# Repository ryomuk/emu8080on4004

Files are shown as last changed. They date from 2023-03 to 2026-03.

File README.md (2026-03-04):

# emu8080on4004
Intel 8080 Emulator on 4004 Evaluation Board

This document is written mostly in Japanese.
If necessary, please use a translation service such as DeepL (I recommend this) or Google.

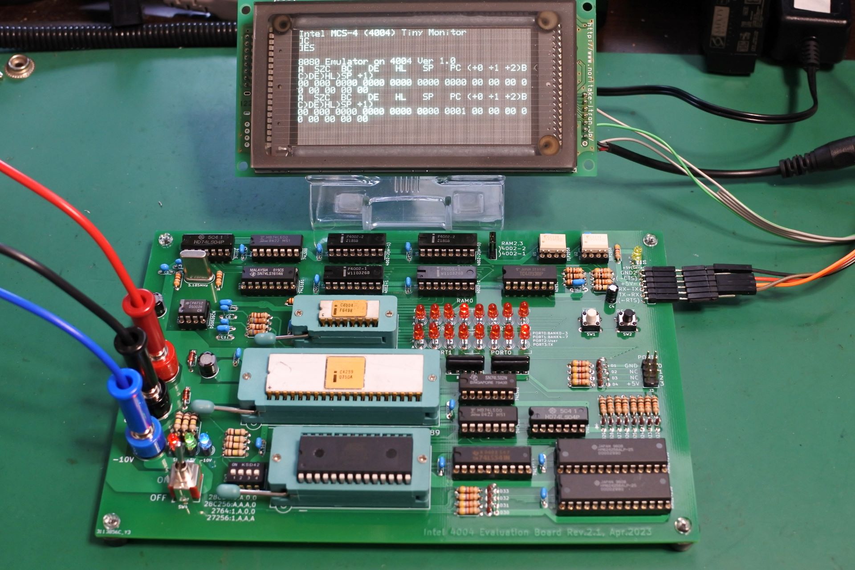
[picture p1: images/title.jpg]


## 概要
自作の4004実験用ボードと，その上で動作する8080エミュレータです．Palo Alot Tiny BASIC(4K整数型BASIC)や，Grant Searle's BASIC(8K浮動小数点BASIC)の8080移植版がほぼそのまま動くレベルの機能が実現できています．動作速度は8080実機の1/700程度です．

## 制限事項等
- P(パリティ)フラグの実装は正確ではありません．{J,C,R}{PO,PE}実行時にAレジスタの値から計算されます．
- DAA命令の実装は正確ではありません．
- IN命令(コントロールレジスタ)はACC=0xFF(データあり)を返します．
- IN命令(データレジスタ)は4004ボードのソフトウェアで実装されたUARTのGETCHARを呼ぶので，入力されるまで止まります．
- OUT命令はAレジスタを4004ボードのシリアルポートに出力します．
- 割り込み関連命令(DI, EI)は未実装です．

## 実験ボードの仕様
### ブレッドボード版プロトタイプの仕様
- CPU: Intel 4004
- Clock: 740kHz
- DATA RAM: 4002-1 x 2 + 4002-2 x 2 (計320bit x 4)
- Program Memory
  - ROM: AT28C64B (8k x 8bit EEPROM)
    - 000H〜EFFHの3.75KB利用可能
  - RAM: HM6268(4k x 4bit SRAM)x 2個
    - 物理メモリ F00H〜FFDHの254byte x 16バンク
      (上記を論理メモリ 000H〜FDFHにマッピングしてアクセス)
- 通信ポート: 9600bps Software Serial UART (TTL level)

### Rev.2.1版の仕様(ブレッドボード版との差分)
- Program Memory
  - DATA RAM: ピンヘッダの設定により4002-1 x 4の構成も可能ですが，その場合はソフトウェアでRAM2, RAM3をアクセスしている部分を修正する必要があります．
  - ROM: AT28C64B, AT28C256, 2764, 27256をDIPスイッチで選択可能なように設計しましたが，動作確認はAT28C64Bで実施．それ以外は未確認です．
  - RAM: HM624256(1Mbit(256k x 4bit) SRAM)x 2個
    - 物理メモリ F00H〜FFDHの254byte x 256バンク
      (上記を論理メモリ 0000H〜FDFFHにマッピングしてアクセス)

## ToDO
- メモリ64KBに拡張 → Rev.2.1で実現(2023/4/12)
- プリント基板作成 → Rev.2.1で実現(2023/4/12)
- IN命令時にTESTキーを使ったSTOPボタン相当の機能の実装

## 動画
Youtubeで関連動画を公開しています．
- https://www.youtube.com/@ryomukai/videos

## ブログ
関連する情報が書いてあるかも．
- [Intel 4004関連記事のまとめ](https://note.com/ryomuk/m/m2f55e2a1f586)

## 4004関連開発事例
- [Intel 4004  50th Anniversary Project](https://www.4004.com/)
  - https://www.4004.com/busicom-replica.html
  - http://www.4004.com/2009/Busicom-141PF-Calculator_asm_rel-1-0-1.txt
- https://github.com/jim11662418/4004-SBC
- https://www.cpushack.com/mcs-4-test-boards-for-sale
- https://github.com/novi/4004MainBoard

## データシート
- http://www.bitsavers.org/components/intel/
- https://www.intel-vintage.info/intelmcs.htm

## 開発環境
- [The Macroassembler AS](http://john.ccac.rwth-aachen.de:8000/as/)

## 画像集
- ブレッドボード版のプロトタイプ
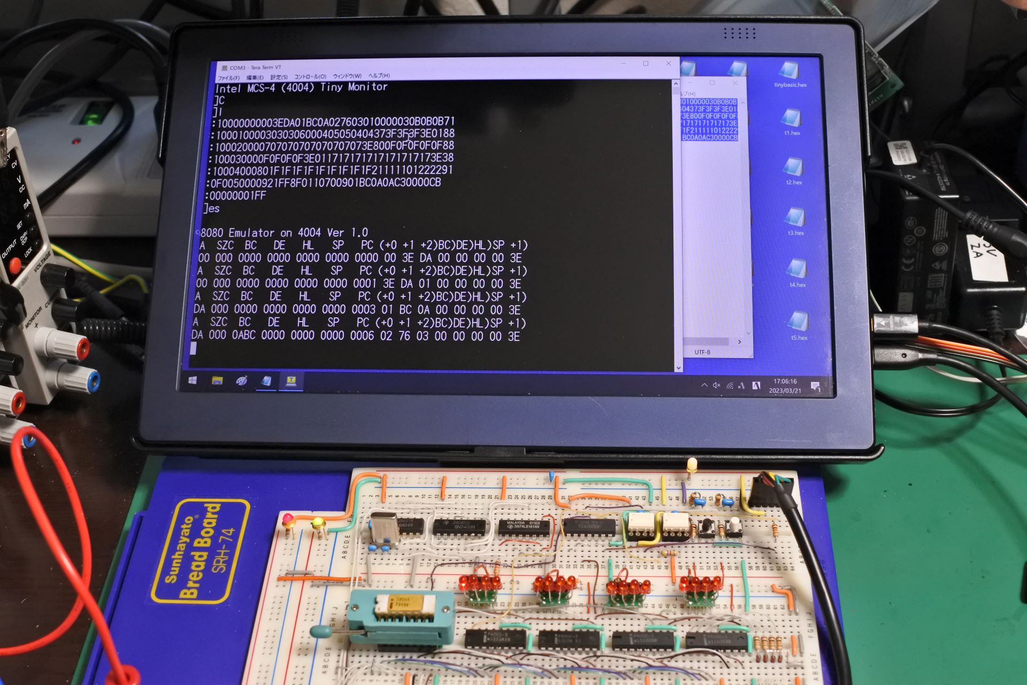
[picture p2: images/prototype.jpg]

- プロトタイプでPalo Alto BASIC実行

- Rev.2.1基板
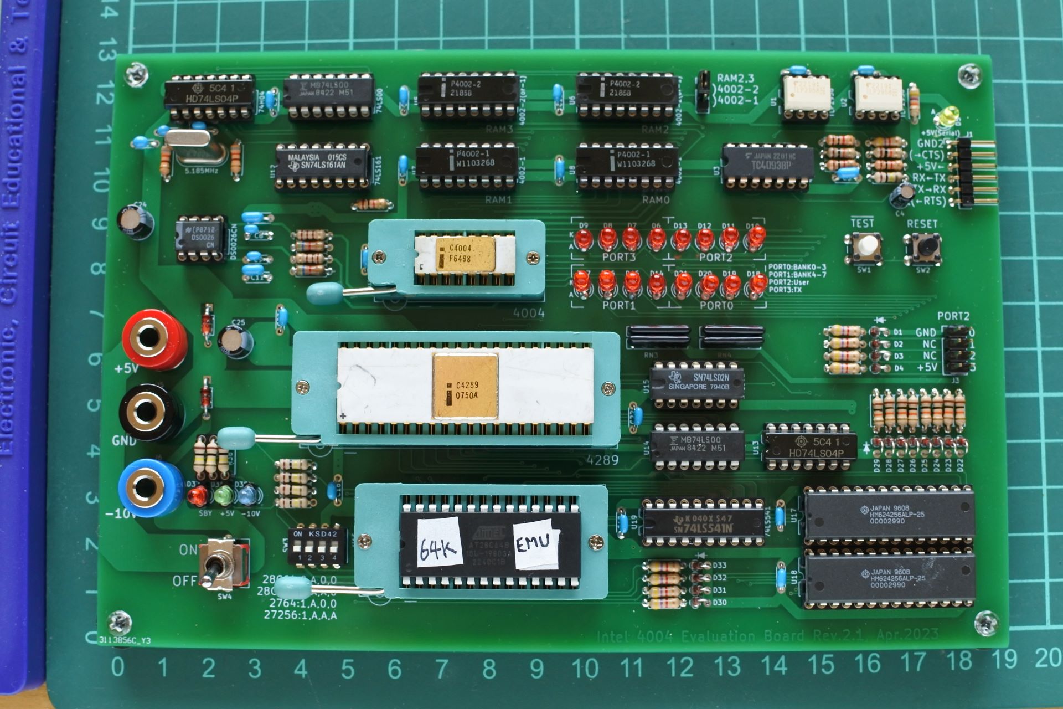
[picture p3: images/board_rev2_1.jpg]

- ブレッドボード版とRev.2.1基板
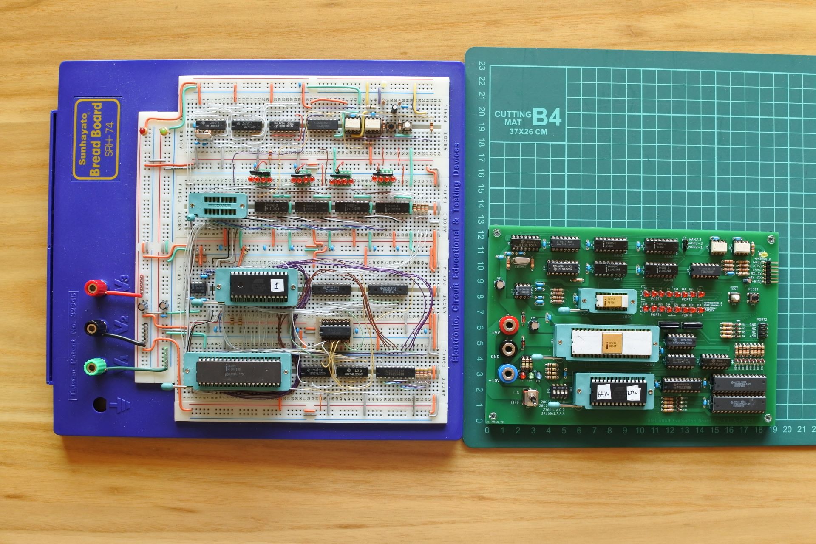
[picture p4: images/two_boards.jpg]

- 8K BASIC 起動画面
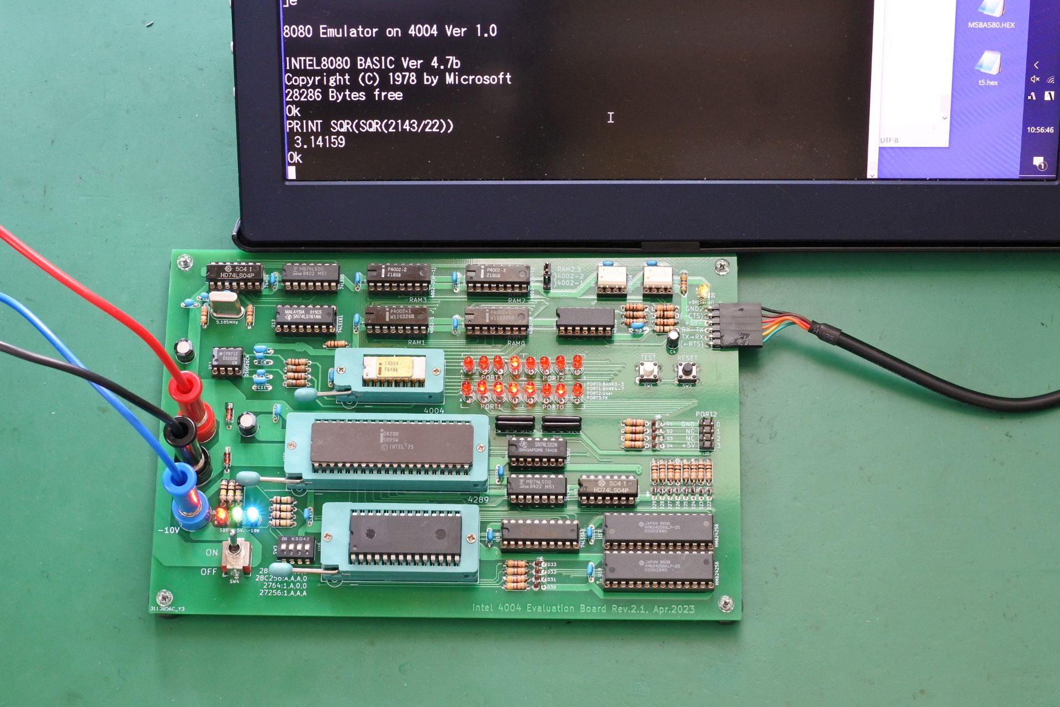
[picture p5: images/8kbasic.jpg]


## 更新履歴
- 2023/3/21: 初版公開
- 2023/4/3: SUBフラグ(NEC uPD8080A, uCOM-80用)に関するコードを削除
- 2023/4/12: 基板(Rev.2.1)に合わせていろいろ更新．ブレッドボード版はprototypeフォルダに移動
- 2023/4/15: emu.asmにレジスタ表示しながらの連続実行とTESTボタンでの停止機能を追加
- 2023/4/16: ADC, ACIにバグ(0+FFH+Carrry(1)でCarryが立たない)があったので修正．

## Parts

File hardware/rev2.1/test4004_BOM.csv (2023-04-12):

# | Reference | Qty | Value | Memo | URL | Footprint | Example | Whare to buy
1 | C1, C2, C5, C6, C13, C14, C15, C16, C17, C18, C19, C20, C21, C22, C23 | 15 | 0.1uF |  | https://akizukidenshi.com/catalog/g/gP-10147/ | 000_MyFootprint:C_Disc_D4.3mm_W1.9mm_P5.00mm
2 | C3, C7, C11 | 3 | 1uF |  | https://akizukidenshi.com/catalog/g/gP-08150/ | 000_MyFootprint:C_Disc_D4.7mm_W2.5mm_P5.00mm
3 | C4 | 1 | 10uF |  | https://akizukidenshi.com/catalog/g/gP-10590/ | 000_MyFootprint:CP_Radial_D4.0mm_P1.50mm
4 | C8, C9, C10 | 3 | 0.01uF |  | https://akizukidenshi.com/catalog/g/gP-10148/ | 000_MyFootprint:C_Disc_D4.3mm_W1.9mm_P5.00mm
5 | C12 | 1 | 50pF | 47pF可 | https://akizukidenshi.com/catalog/g/gP-08045/ | 000_MyFootprint:C_Disc_D4.3mm_W1.9mm_P5.00mm
6 | C24, C25 | 2 | 47uF |  | https://akizukidenshi.com/catalog/g/gP-10596/ | 000_MyFootprint:CP_Radial_D6.3mm_P2.50mm
7 | D1, D2, D3, D4, D22, D23, D24, D25, D26, D27, D28, D29, D30, D31, D32, D33 | 16 | 1N4148 |  | https://akizukidenshi.com/catalog/g/gI-00941/ | 000_MyFootprint:D_DO-35_SOD27_P2.54mm_Vertical_AnodeUp
8 | D5, D34, D37, D38 | 4 | LED | 電源表示用のLED(D5, 37, 34, 38)は任意です。それらに接続される抵抗は適当に変更して下さい。 | https://akizukidenshi.com/catalog/g/gI-16908/ | 000_MyFootprint:LED_D3.0mm
9 | D6, D7, D8, D9, D10, D11, D12, D13, D14, D15, D16, D17, D18, D19, D20, D21 | 16 | LED | 4002のポートに接続されるLEDです。低消費電力なものを使用して下さい。 | https://akizukidenshi.com/catalog/g/gI-16908/ | 000_MyFootprint:LED_D3.0mm
11 | D35 | 1 | Zener6.2V | 電源の逆接続防止用です。無くても動作します。 | https://akizukidenshi.com/catalog/g/gI-07494/ | 000_MyFootprint:D_DO-35_SOD27_P7.62mm_Horizontal
12 | D36 | 1 | Zener12V | 電源の逆接続防止用です。無くても動作します。 | https://akizukidenshi.com/catalog/g/gI-06452/ | 000_MyFootprint:D_DO-35_SOD27_P7.62mm_Horizontal
16 | J1 | 1 | L-pinheader 6P |  |  | 000_MyFootprint:PinHeader_1x06_P2.54mm_Horizontal
17 | J2 | 1 | Pin Header 3P |  |  | 000_MyFootprint:PinHeader_1x03_P2.54mm_Vertical
18 | J3 | 1 | Pin Header 6P(2x3) |  |  | 000_MyFootprint:PinHeader_2x04_P2.54mm_Vertical
19 | J4, J5, J6 | 3 | TJ-563 |  | https://eleshop.jp/shop/g/gD6F365/ | 000_MyFootprint:Banana_Jack_1Pin
22 | R1, R2, R3, R4, R7, R32, R33, R34, R35 | 9 | 4.7k |  |  | 000_MyFootprint:R_Axial_DIN0207_L6.3mm_D2.5mm_P7.62mm_Horizontal
23 | R5 | 1 | 47k |  |  | 000_MyFootprint:R_Axial_DIN0207_L6.3mm_D2.5mm_P7.62mm_Horizontal
24 | R6, R9, R11, R13 | 4 | 1k |  |  | 000_MyFootprint:R_Axial_DIN0207_L6.3mm_D2.5mm_P7.62mm_Horizontal
25 | R8, R10, R20, R21, R22, R23, R24, R25, R26, R27 | 10 | 10k |  |  | 000_MyFootprint:R_Axial_DIN0207_L6.3mm_D2.5mm_P7.62mm_Horizontal
26 | R12, R28, R29, R30, R31, R36, R38, R37 | 6 | 100k |  |  | 000_MyFootprint:R_Axial_DIN0207_L6.3mm_D2.5mm_P7.62mm_Horizontal
27 | R14, R15 | 2 | 110 |  |  | 000_MyFootprint:R_Axial_DIN0207_L6.3mm_D2.5mm_P7.62mm_Horizontal
28 | R16, R17 | 2 | 820 |  |  | 000_MyFootprint:R_Axial_DIN0207_L6.3mm_D2.5mm_P7.62mm_Horizontal
29 | R18, R19 | 2 | 5.6k |  |  | 000_MyFootprint:R_Axial_DIN0207_L6.3mm_D2.5mm_P7.62mm_Horizontal
31 | RN1, RN2, RN3, RN4 | 4 | 100k |  |  | 000_MyFootprint:R_Array_SIP5
32 | SW1,SW2 | 1 | push sw |  | https://akizukidenshi.com/catalog/g/gP-03647/ | 000_MyFootprint:SW_PUSH_6mm_H4.3mm
34 | SW3 | 1 | dip sw 4P |  | https://akizukidenshi.com/catalog/g/gP-08923/ | 000_MyFootprint:SW_DIP_SPSTx04_Slide_6.7x11.72mm_W7.62mm_P2.54mm_LowProfile
35 | SW4 | 1 | toggle sw | 2MD1-T1-B4-VS2-Q-E | https://akizukidenshi.com/catalog/g/gP-04028/ | 000_MyFootprint:SW_DPDT_Toggle_with_mount
36 | U1, U2 | 2 | TLP2958 |  | digikey, mouser, kashinoki(https://www.kashinoki.shop/?pid=140502153) | 000_MyFootprint:DIP-8_W7.62mm
37 | U3 | 1 | 4093B |  | https://eleshop.jp/shop/g/gT11932/ | 000_MyFootprint:DIP-14_W7.62mm
38 | U4 | 1 | Intel 4004 |  | ebay | 000_MyFootprint:DIP_Socket-16_W4.3_W5.08_W7.62_W10.16_W10.9_3M_216-3340-00-0602J
 | U4 |  |  | ZIF socket 16P | https://akizukidenshi.com/catalog/g/gP-12074/
39 | U5, U6 | 2 | Intel 4002-2 |  | ebay | 000_MyFootprint:DIP-16_W7.62mm
40 | U7, U8 | 2 | Intel 4002-1 |  | ebay | 000_MyFootprint:DIP-16_W7.62mm
41 | U9 | 1 | 74H04 | 74LS04可 | wakamatsu | 000_MyFootprint:DIP-14_W7.62mm
42 | U10, U14 | 2 | 74LS00 |  |  | 000_MyFootprint:DIP-14_W7.62mm
43 | U11 | 1 | DS0026CN |  | wakamatsu | 000_MyFootprint:DIP-8_W7.62mm
44 | U12 | 1 | 74LS161 |  |  | 000_MyFootprint:DIP-16_W7.62mm
45 | U13 | 1 | 74LS04 |  |  | 000_MyFootprint:DIP-14_W7.62mm
46 | U15 | 1 | 74LS02 |  |  | 000_MyFootprint:DIP-14_W7.62mm
47 | U16 | 1 | 28C64B |  | ebay, digikey | 000_MyFootprint:DIP_Socket-28_W11.9_W12.7_W15.24_W17.78_W18.5_3M_228-1277-00-0602J
 | U16 |  |  | ZIF socket 28P | https://akizukidenshi.com/catalog/g/gP-11743/
48 | U17, U18 | 2 | HM624256 |  | ebay | 000_MyFootprint:DIP-28_W10.16mm
49 | U19 | 1 | 74LS541 |  |  | 000_MyFootprint:DIP-20_W7.62mm
50 | U20 | 1 | Intel 4289 |  | ebay | 000_MyFootprint:DIP_Socket-40_W11.9_W12.7_W15.24_W17.78_W18.5_3M_240-1280-00-0602J
 | U20 |  |  | ZIF socket 40P | https://akizukidenshi.com/catalog/g/gP-11744/
51 | Y1 | 1 | 5.185MHz |  | ebay, digikey, wakamatsu | 000_MyFootprint:Crystal_HC49-U_Vertical

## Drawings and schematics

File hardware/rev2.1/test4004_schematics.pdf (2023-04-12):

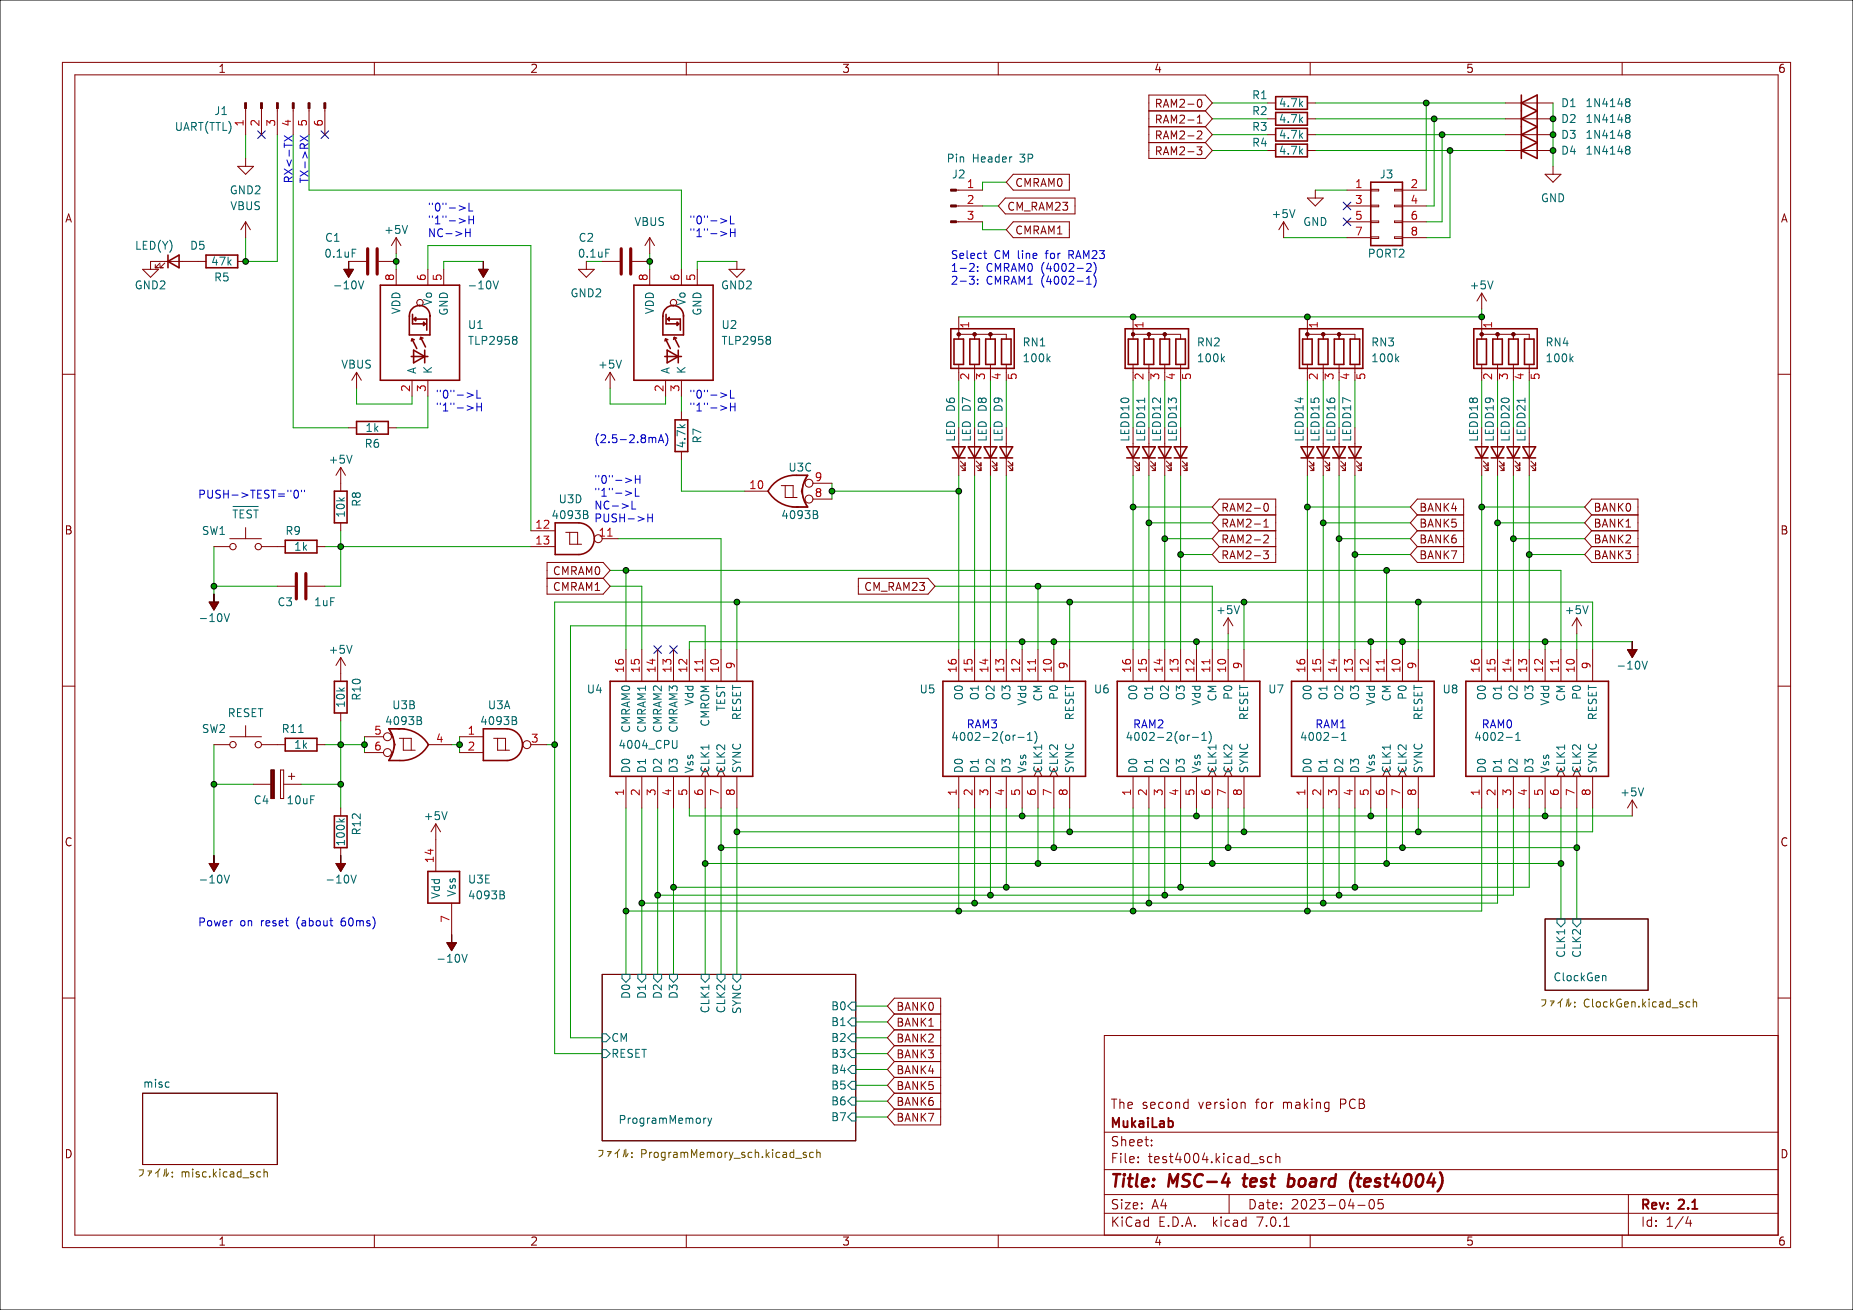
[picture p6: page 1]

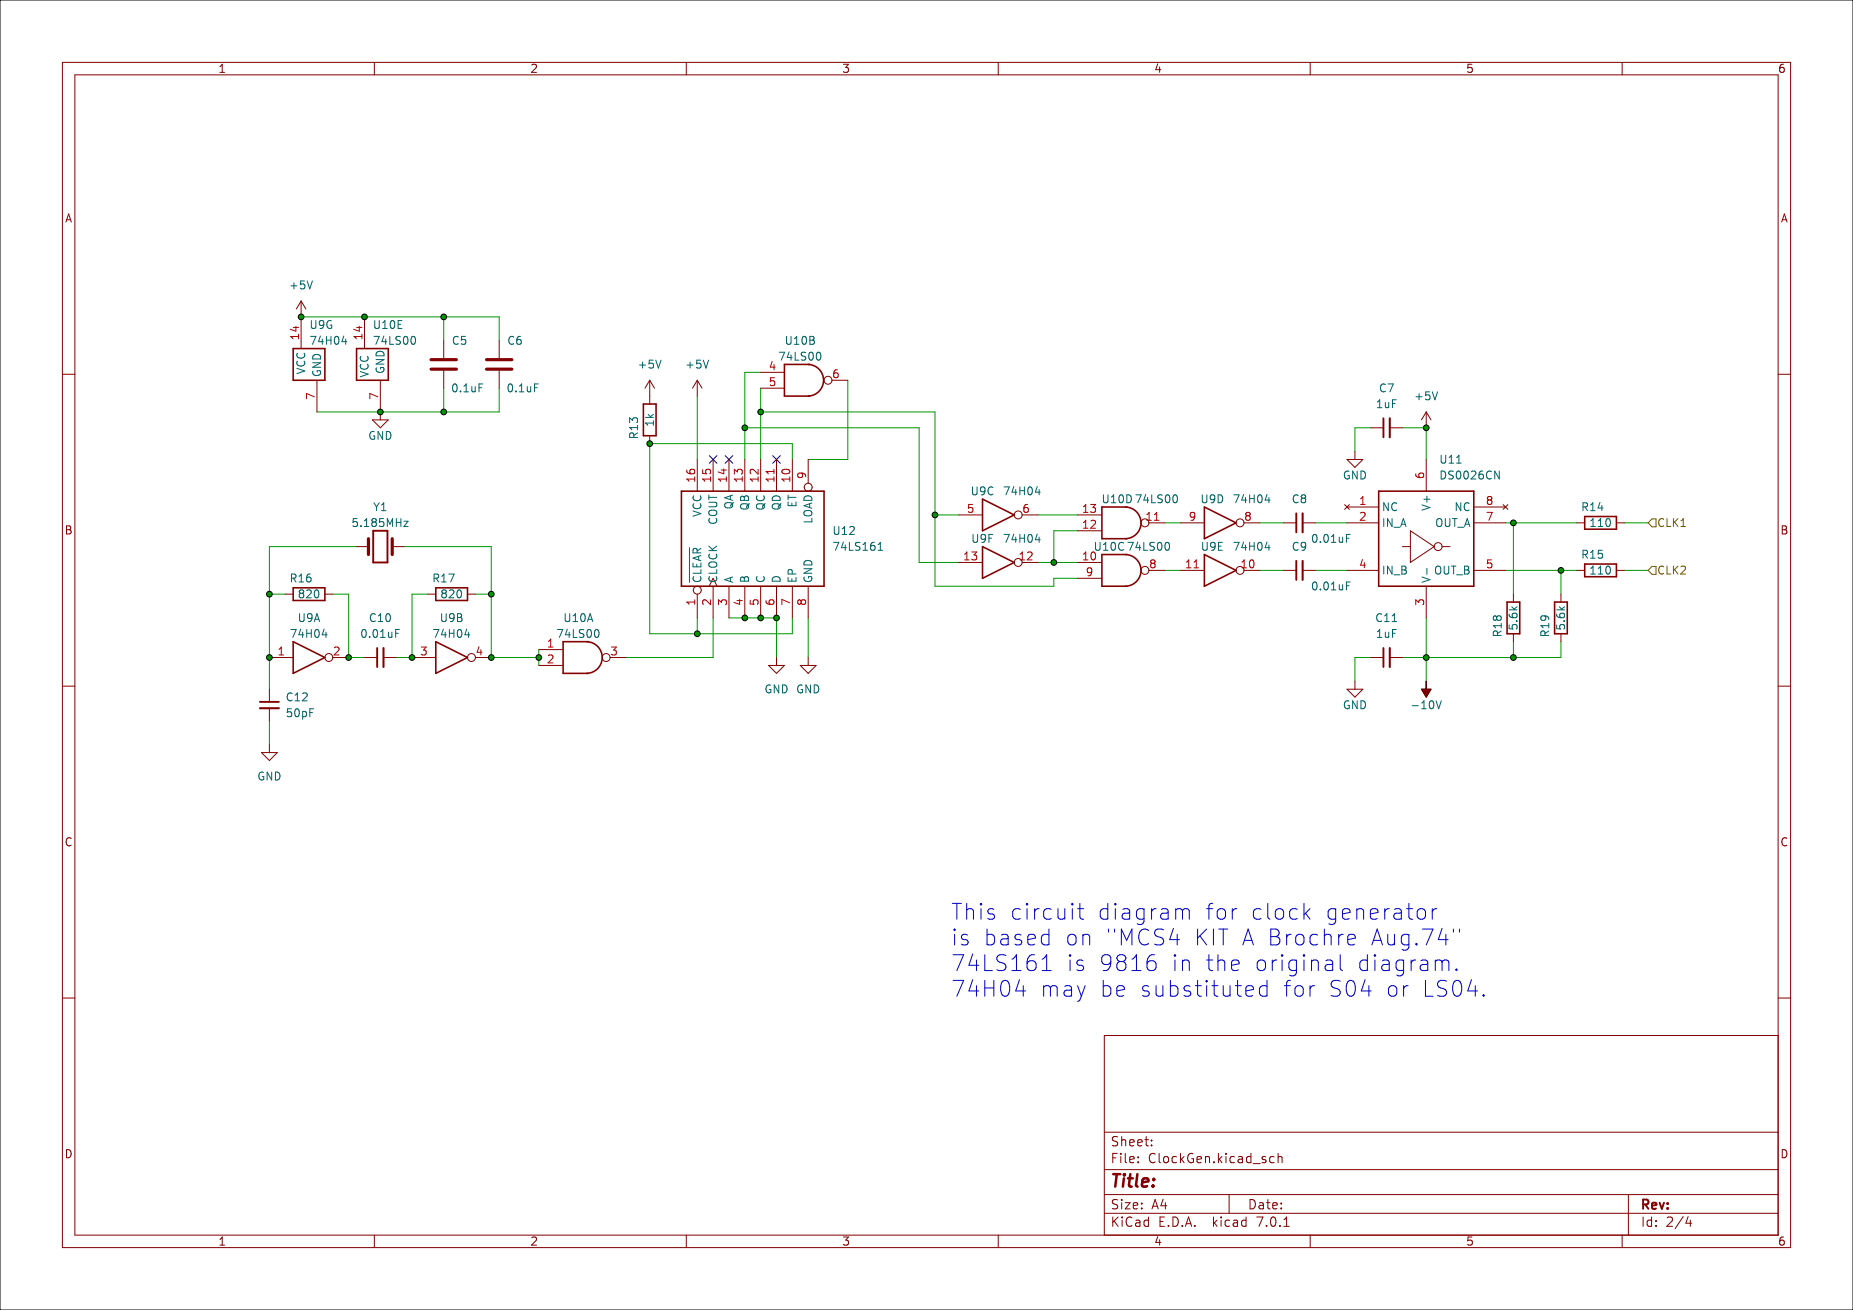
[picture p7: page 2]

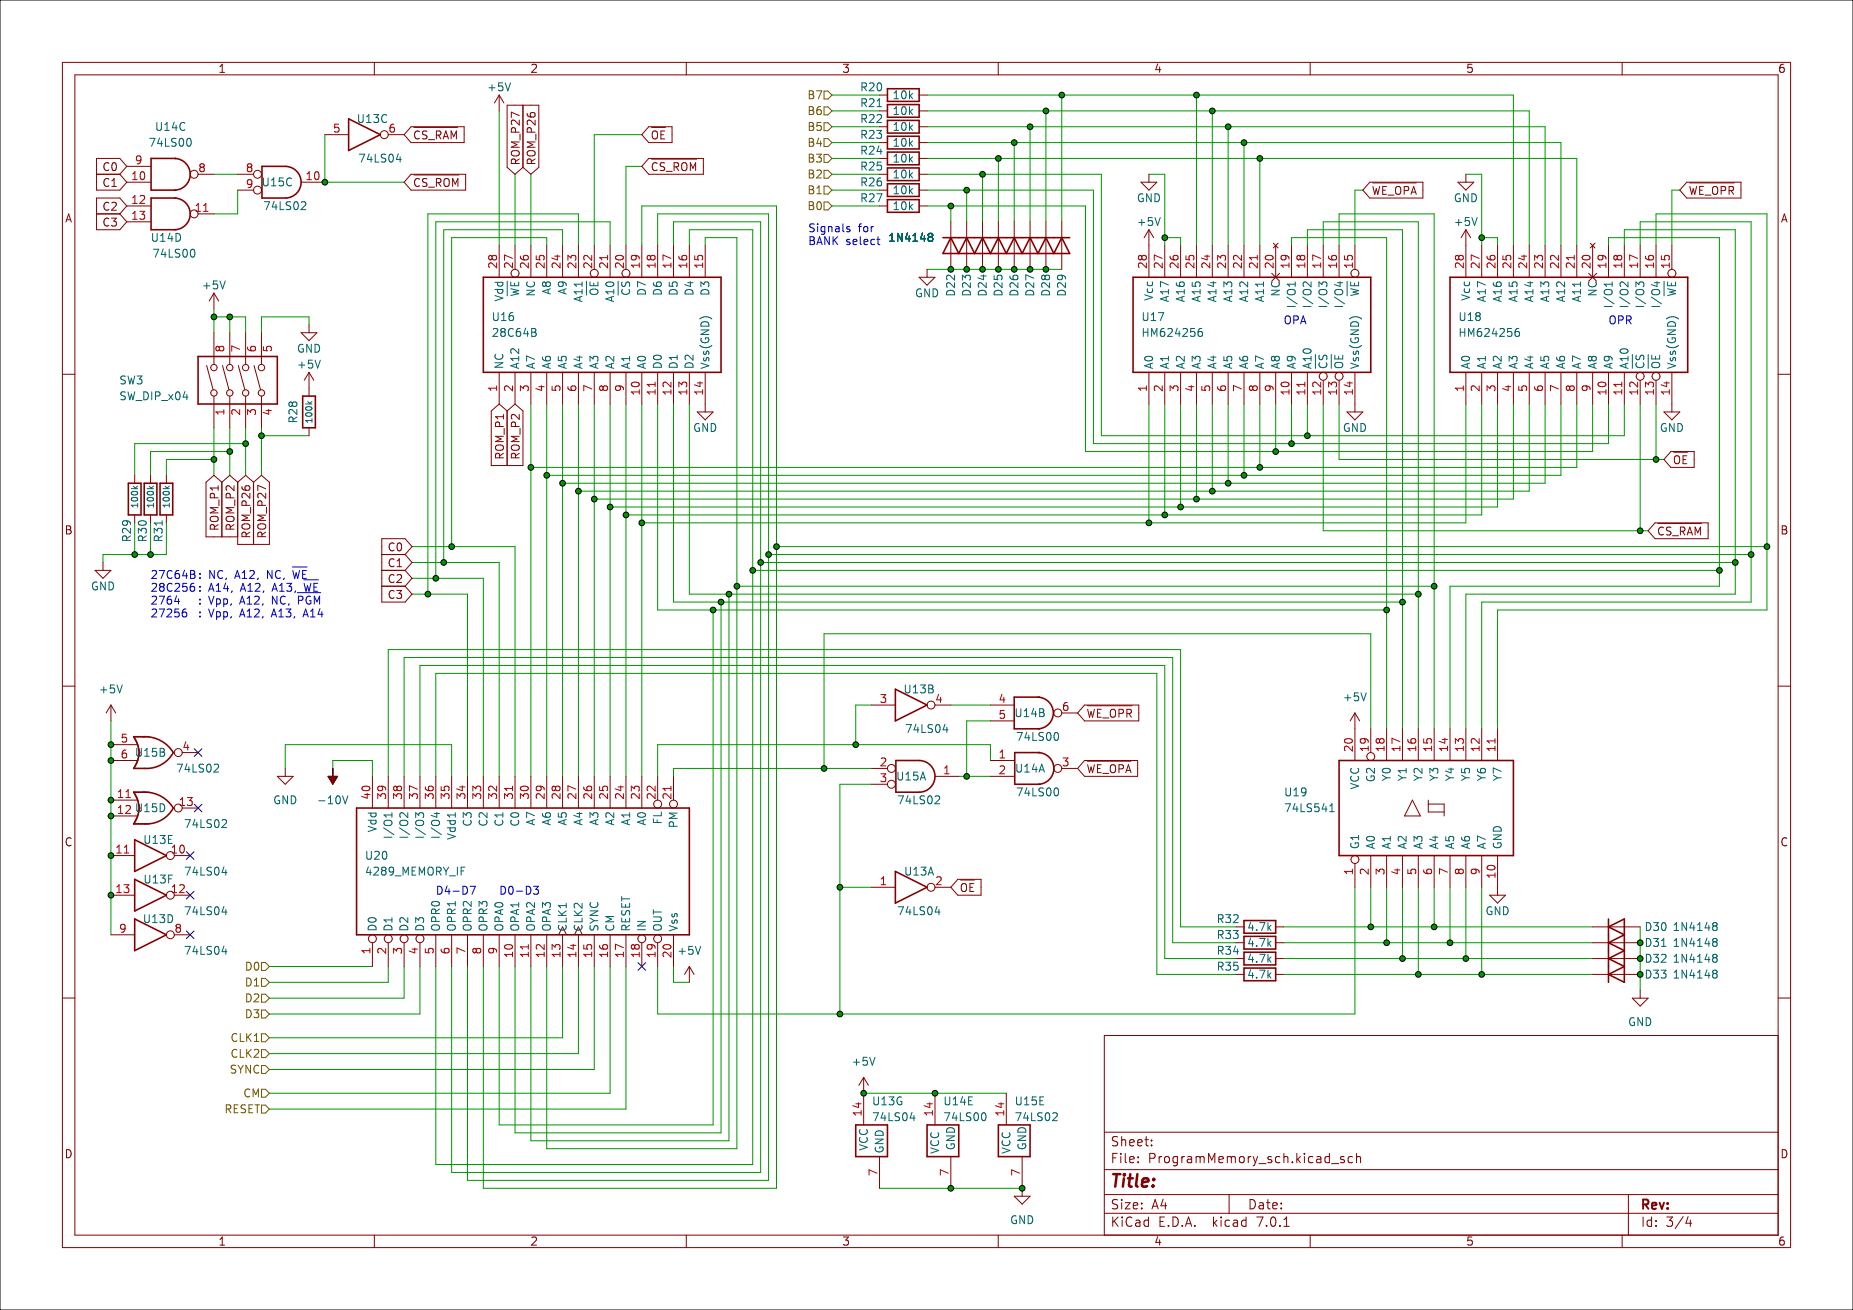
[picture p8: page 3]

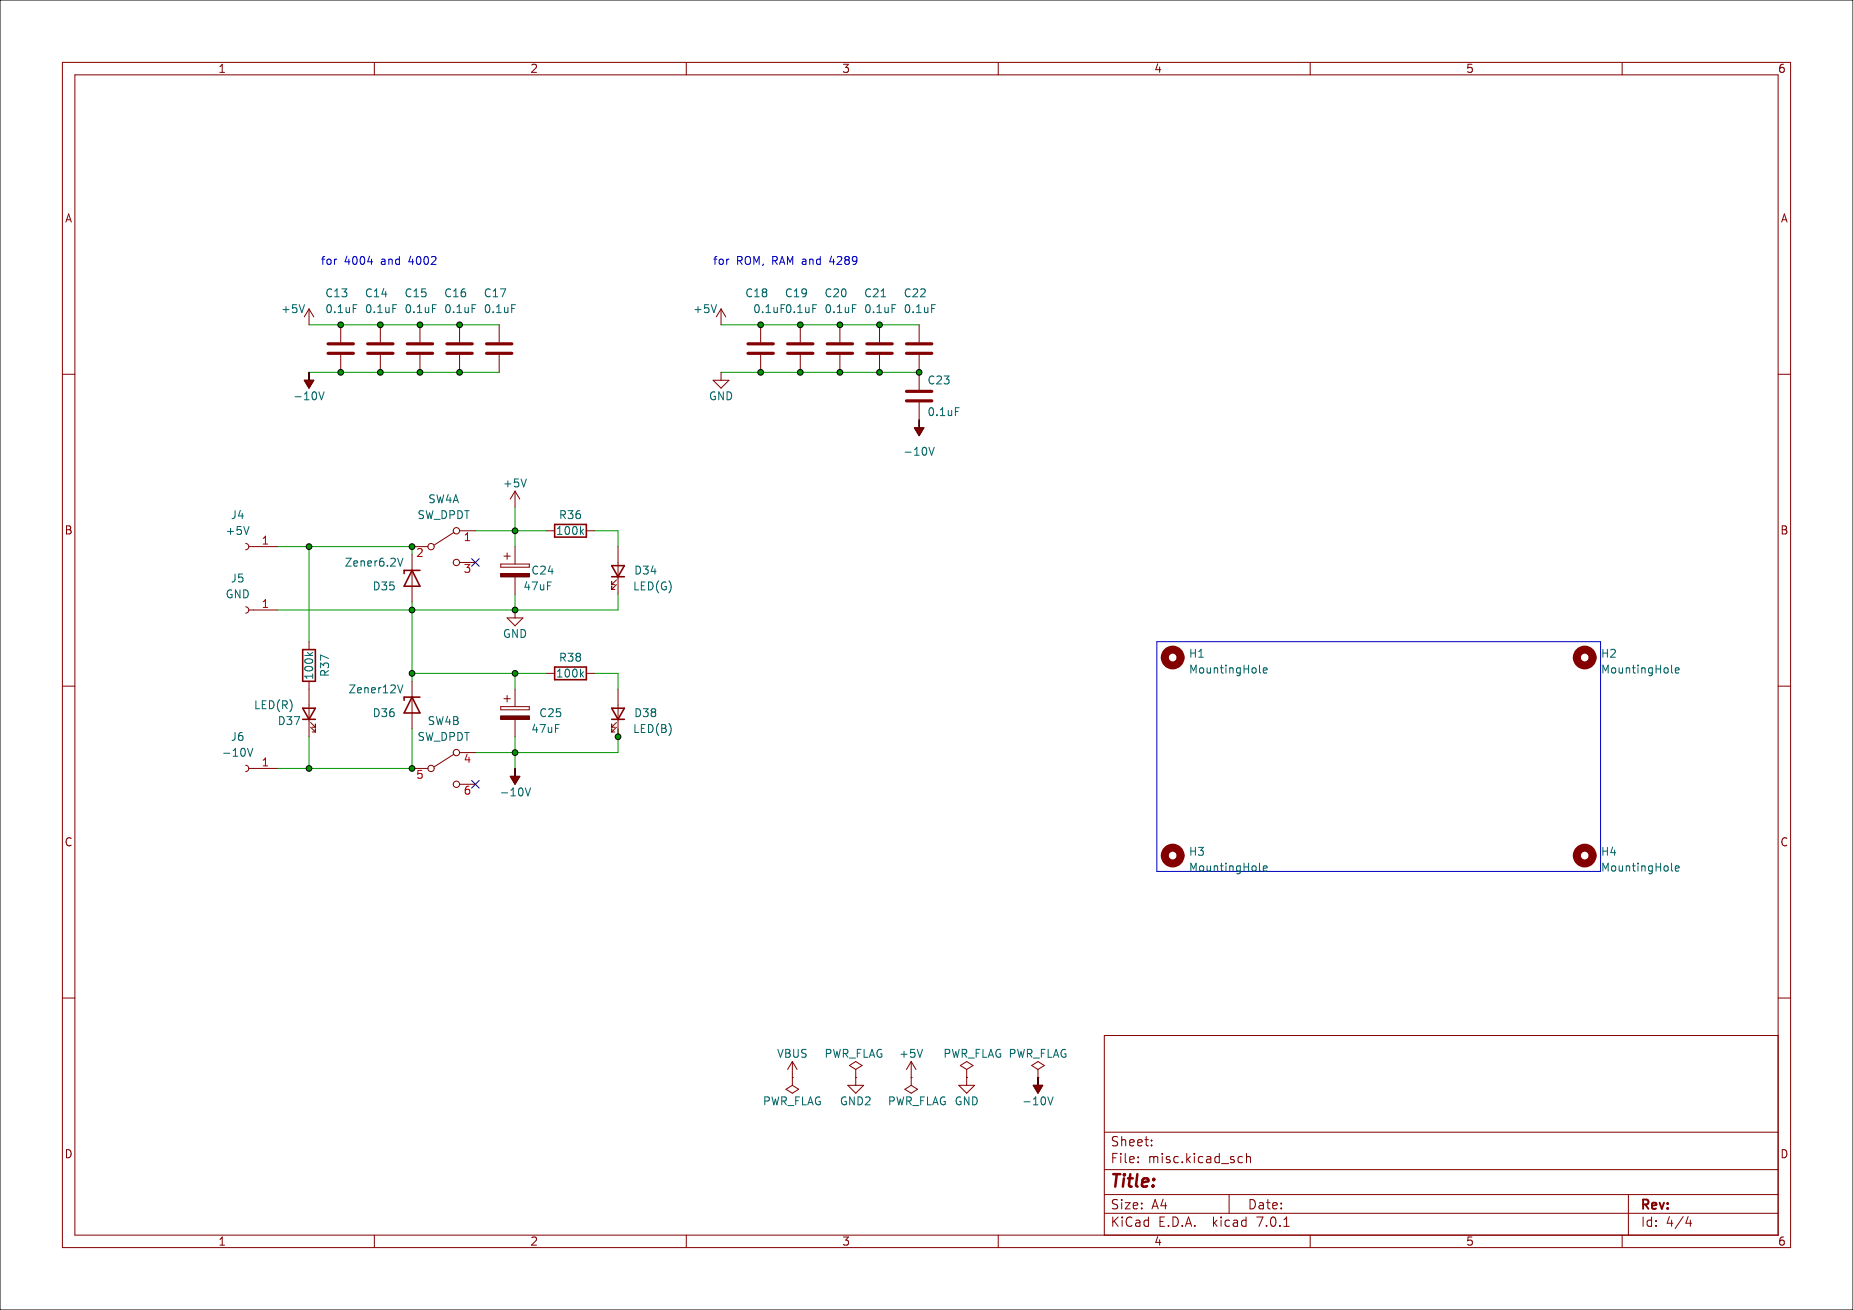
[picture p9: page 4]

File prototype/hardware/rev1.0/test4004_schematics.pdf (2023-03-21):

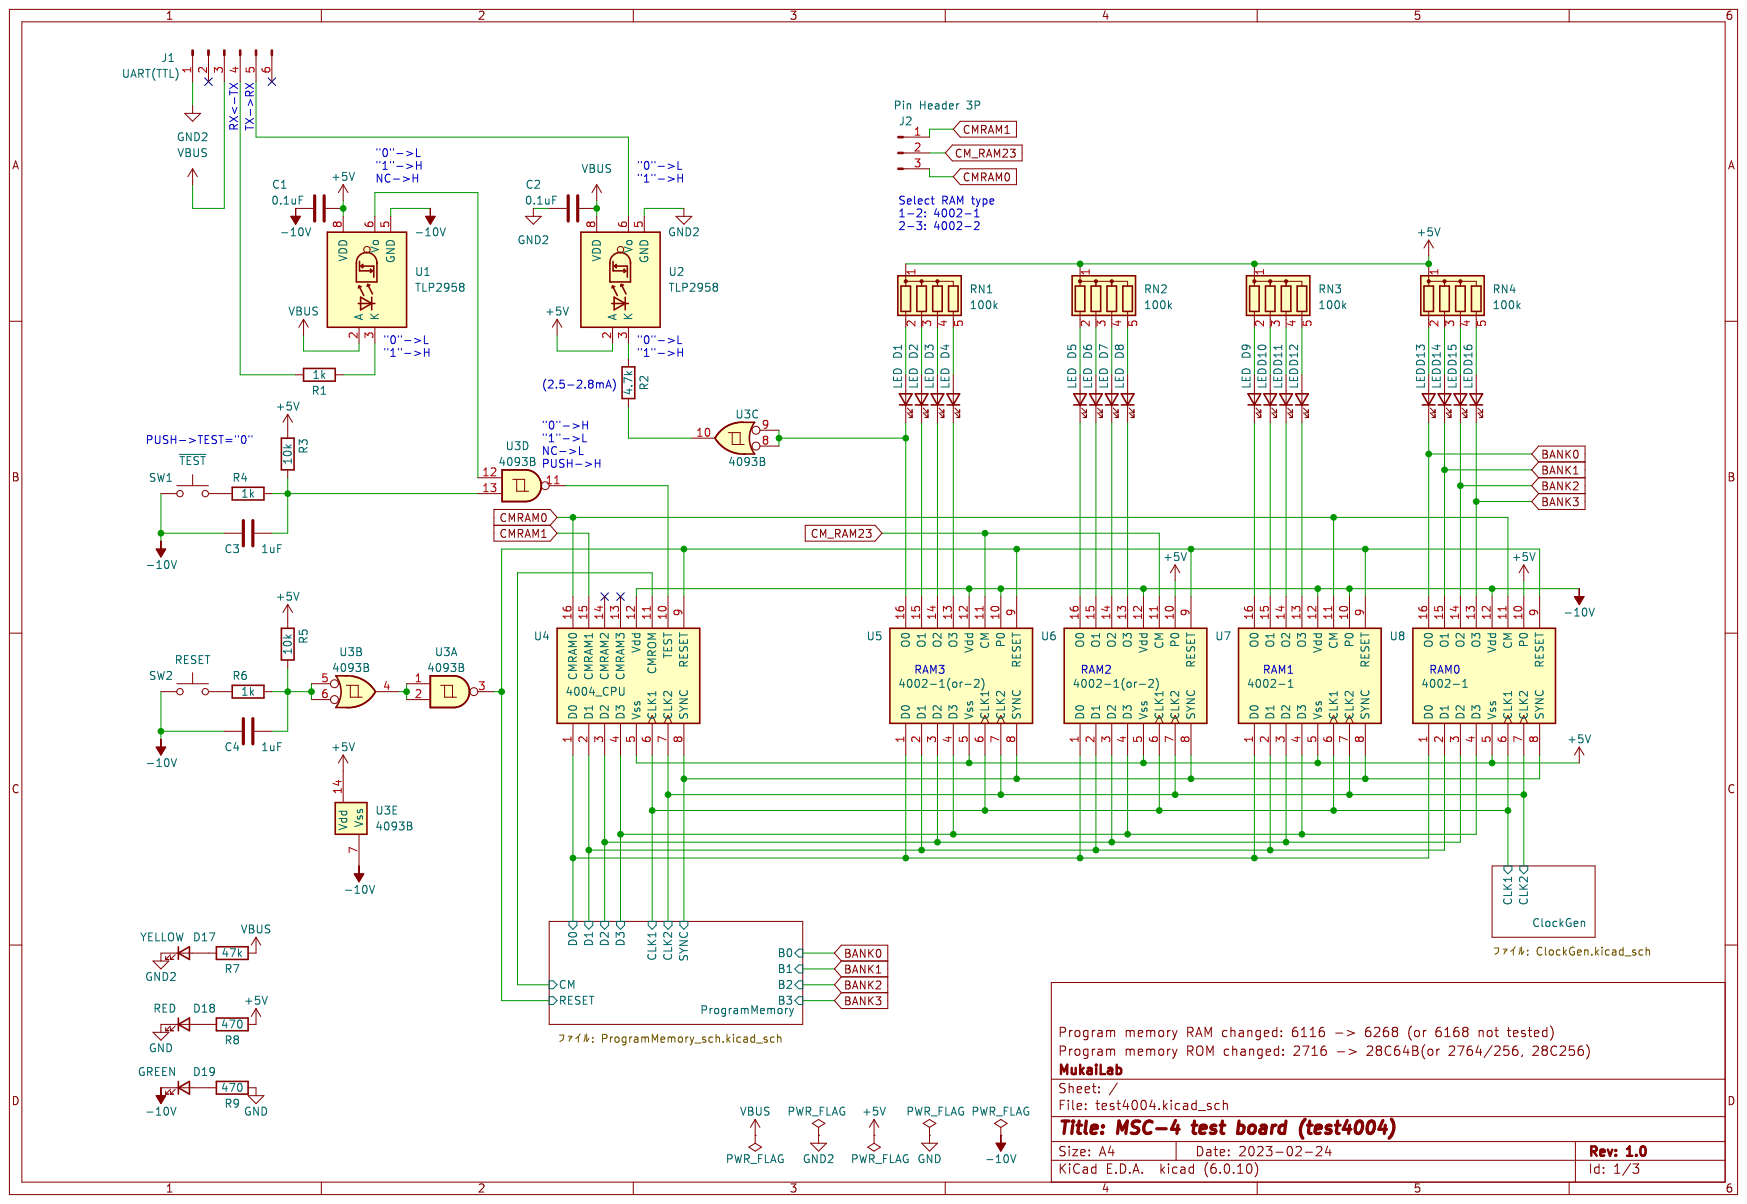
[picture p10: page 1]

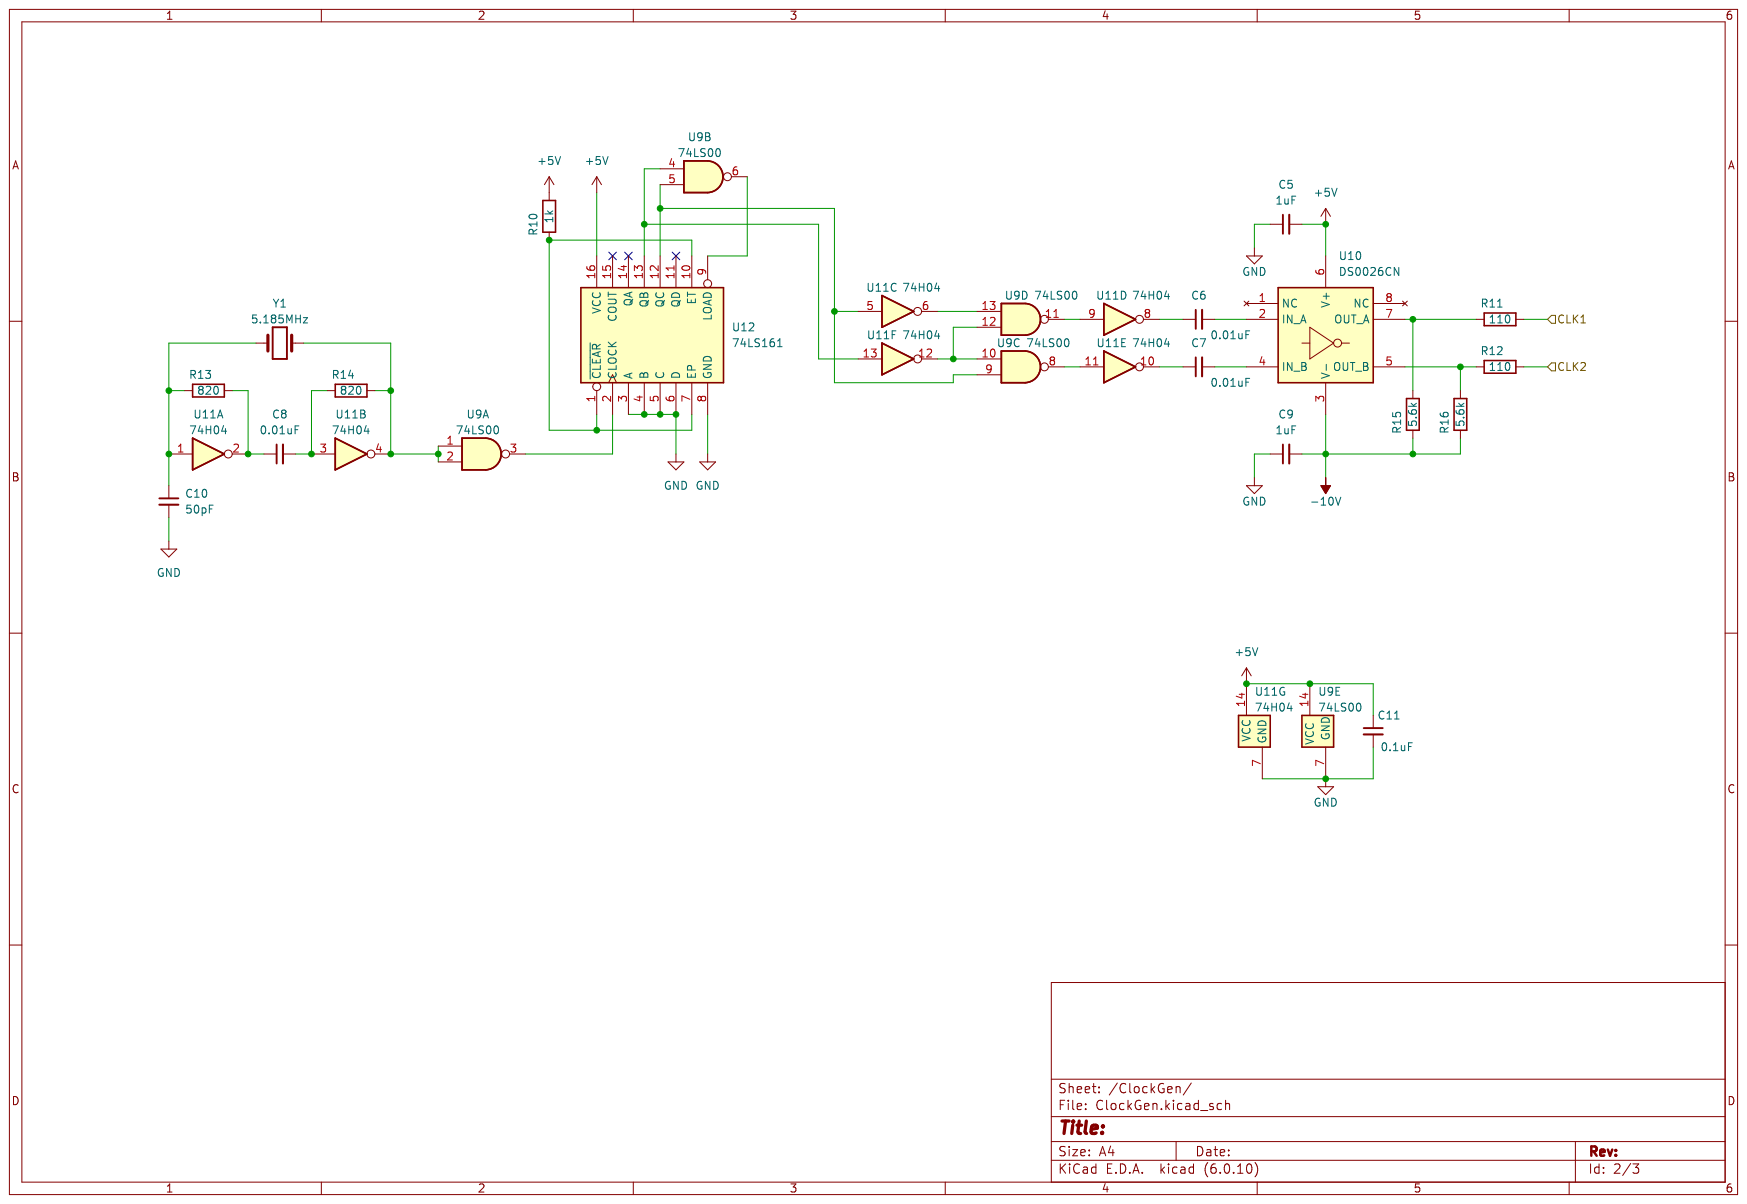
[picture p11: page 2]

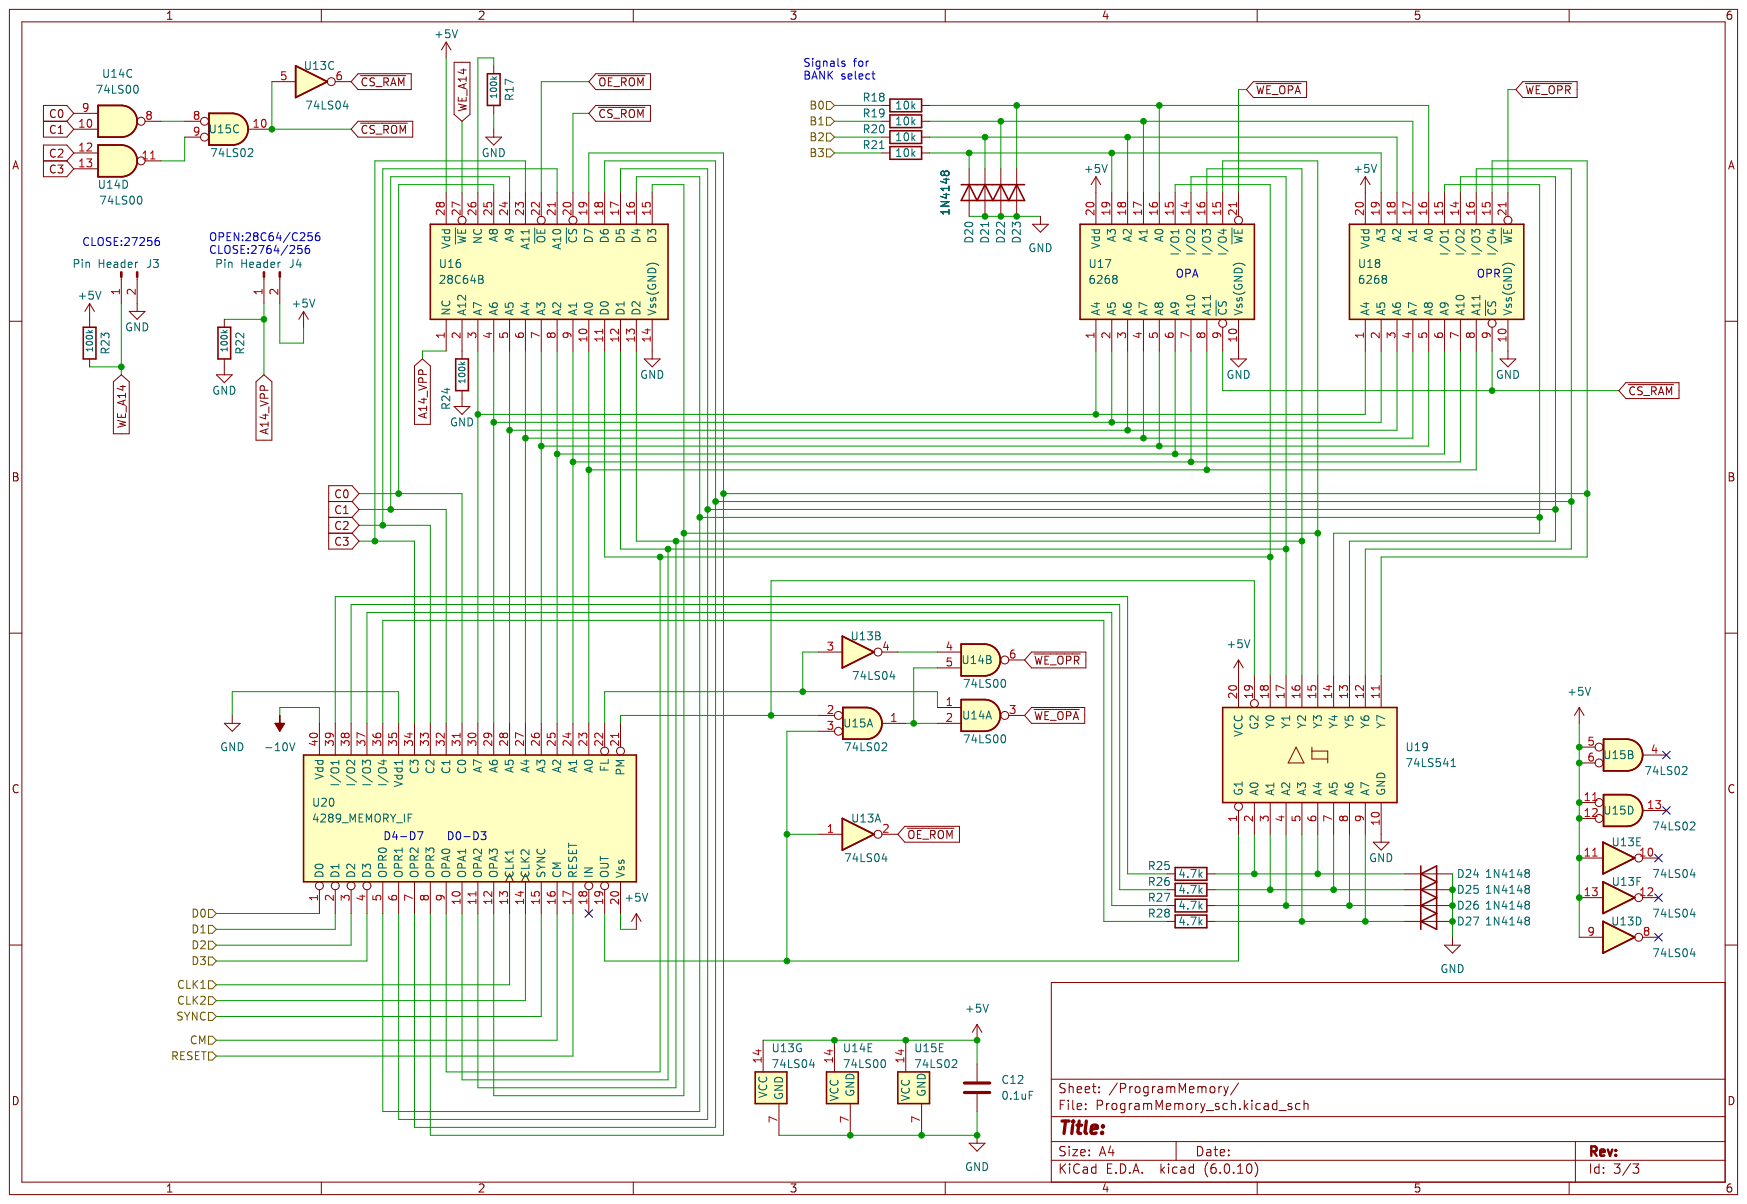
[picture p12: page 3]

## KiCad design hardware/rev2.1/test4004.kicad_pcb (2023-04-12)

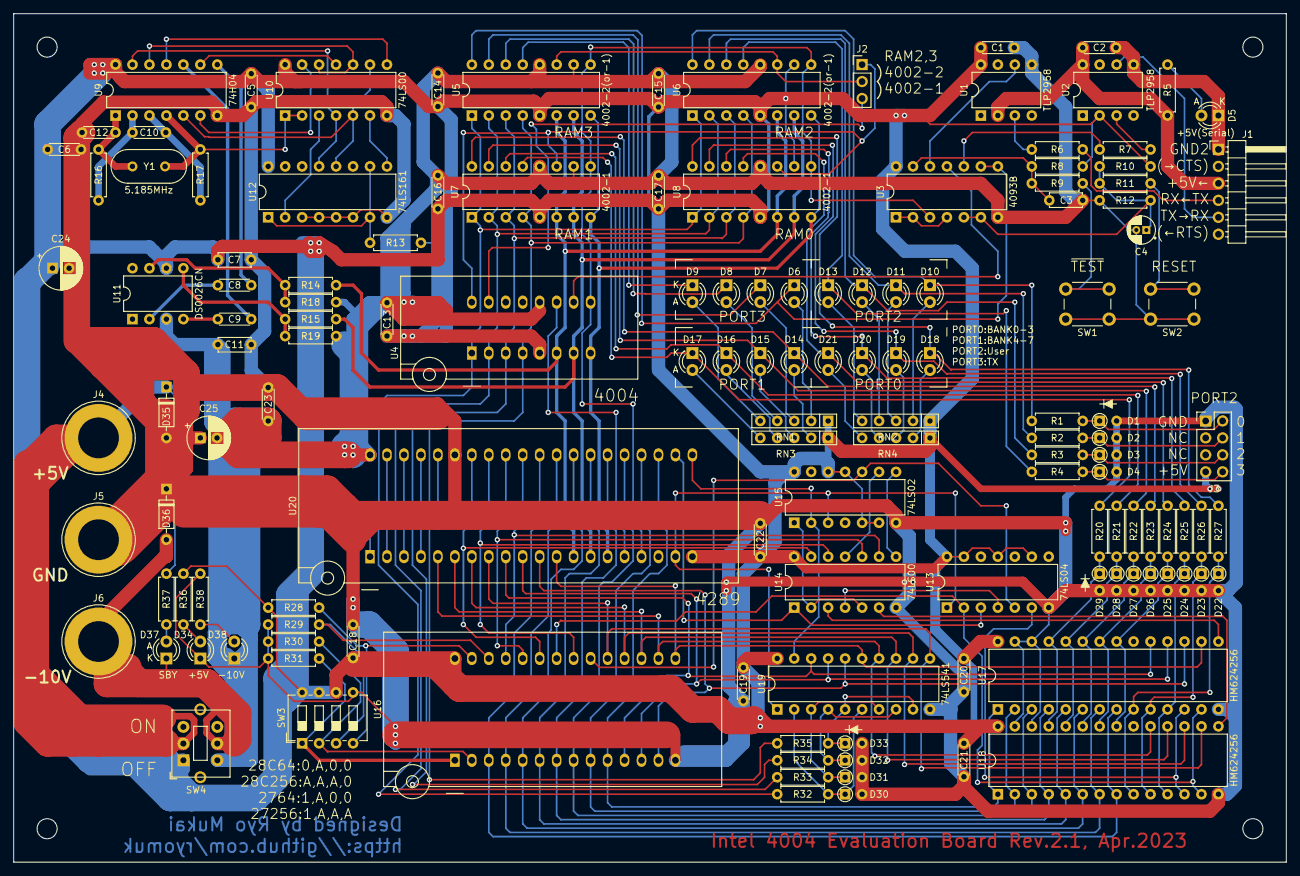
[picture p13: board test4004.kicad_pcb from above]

Board: 2 copper layers, 190.5 x 127.0 mm, 140 parts (0 on the bottom side), 142 nets.

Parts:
C1, C2, C5, C6, C13, C14, C15, C16, C17, C18, C19, C20, C21, C22, C23: 0.1uF; C_Disc_D4.3mm_W1.9mm_P5.00mm
C3, C7, C11: 1uF; C_Disc_D4.7mm_W2.5mm_P5.00mm
C4: 10uF; CP_Radial_D4.0mm_P1.50mm
C8, C9, C10: 0.01uF; C_Disc_D4.3mm_W1.9mm_P5.00mm
C12: 50pF; C_Disc_D4.3mm_W1.9mm_P5.00mm
C24, C25: 47uF; CP_Radial_D6.3mm_P2.50mm
D1, D2, D3, D4, D22, D23, D24, D25, D26, D27, D28, D29, D30, D31, D32, D33: 1N4148; D_DO-35_SOD27_P2.54mm_Vertical_AnodeUp
D5: YELLOW; LED_D3.0mm
D6, D7, D8, D9, D10, D11, D12, D13, D14, D15, D16, D17, D18, D19, D20, D21: LED; LED_D3.0mm
D34: TLR101; LED_D3.0mm
D35: Zener6.2V; D_DO-35_SOD27_P7.62mm_Horizontal
D36: Zener12V; D_DO-35_SOD27_P7.62mm_Horizontal
D37: RED; LED_D3.0mm
D38: TLG101; LED_D3.0mm
H1, H2, H3, H4: MountingHole; MountingHole_3mm
J1: UART(TTL); PinHeader_1x06_P2.54mm_Horizontal
J2: Pin Header 3P; PinHeader_1x03_P2.54mm_Vertical
J3: PORT2; PinHeader_2x04_P2.54mm_Vertical
J4: +5V; Banana_Jack_1Pin
J5: GND; Banana_Jack_1Pin
J6: -10V; Banana_Jack_1Pin
R1, R2, R3, R4, R7, R32, R33, R34, R35: 4.7k; R_Axial_DIN0207_L6.3mm_D2.5mm_P7.62mm_Horizontal
R5: 47k; R_Axial_DIN0207_L6.3mm_D2.5mm_P7.62mm_Horizontal
R6, R9, R11, R13: 1k; R_Axial_DIN0207_L6.3mm_D2.5mm_P7.62mm_Horizontal
R8, R10, R20, R21, R22, R23, R24, R25, R26, R27: 10k; R_Axial_DIN0207_L6.3mm_D2.5mm_P7.62mm_Horizontal
R12, R28, R29, R30, R31, R37: 100k; R_Axial_DIN0207_L6.3mm_D2.5mm_P7.62mm_Horizontal
R14, R15: 110; R_Axial_DIN0207_L6.3mm_D2.5mm_P7.62mm_Horizontal
R16, R17: 820; R_Axial_DIN0207_L6.3mm_D2.5mm_P7.62mm_Horizontal
R18, R19: 5.6k; R_Axial_DIN0207_L6.3mm_D2.5mm_P7.62mm_Horizontal
R36, R38: 470; R_Axial_DIN0207_L6.3mm_D2.5mm_P7.62mm_Horizontal
RN1, RN2, RN3, RN4: 100k; R_Array_SIP5
SW1: ~{TEST}; SW_PUSH_6mm_H4.3mm
SW2: RESET; SW_PUSH_6mm_H4.3mm
SW3: SW_DIP_x04; SW_DIP_SPSTx04_Slide_6.7x11.72mm_W7.62mm_P2.54mm_LowProfile
SW4: SW_DPDT; SW_DPDT_Toggle_with_mount
U1, U2: TLP2958; DIP-8_W7.62mm
U3: 4093B; DIP-14_W7.62mm
U4: 4004_CPU; DIP_Socket-16_W4.3_W5.08_W7.62_W10.16_W10.9_3M_216-3340-00-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
U5, U6: 4002-2(or-1); DIP-16_W7.62mm
U7, U8: 4002-1; DIP-16_W7.62mm
U9: 74H04; DIP-14_W7.62mm
U10, U14: 74LS00; DIP-14_W7.62mm
U11: DS0026CN; DIP-8_W7.62mm
U12: 74LS161; DIP-16_W7.62mm
U13: 74LS04; DIP-14_W7.62mm
U15: 74LS02; DIP-14_W7.62mm
U16: 28C64B; DIP_Socket-28_W11.9_W12.7_W15.24_W17.78_W18.5_3M_228-1277-0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
U17, U18: HM624256; DIP-28_W10.16mm
U19: 74LS541; DIP-20_W7.62mm
U20: 4289_MEMORY_IF; DIP_Socket-40_W11.9_W12.7_W15.24_W17.78_W18.5_3M_240-1280-0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
Y1: 5.185MHz; Crystal_HC49-U_Vertical

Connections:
+5V: C1.2, C5.1, C6.1, C7.2, C13.1, C14.1, C15.1, C16.1, C17.1, C18.1, C19.1, C20.1, C21.1, C22.1, C24.1, J3.7, R8.1, R10.1, R13.2, R28.2, R36.1, RN1.1 (common), RN2.1 (common), RN3.1 (common), RN4.1 (common), SW3.6, SW3.7, SW3.8, SW4.1 (A), U1.8 (VDD), U2.2 (A), U3.14 (Vdd), U4.5 (Vss), U5.5 (Vss), U6.5 (Vss), U6.10 (P0), U7.5 (Vss), U8.5 (Vss), U8.10 (P0), U9.14 (VCC), U10.14 (VCC), U11.6 (V+), U12.16 (VCC), U13.9, U13.11, U13.13, U13.14 (VCC), U14.14 (VCC), U15.5, U15.6, U15.11, U15.12, U15.14 (VCC), U16.28 (Vdd), U17.28 (Vcc), U18.28 (Vcc), U19.20 (VCC), U20.20 (Vss)
-10V: C1.1, C3.2, C4.2, C11.2, C13.2, C14.2, C15.2, C16.2, C17.2, C23.2, C25.2, D38.1 (K), R12.2, R18.1, R19.1, SW1.1, SW2.1, SW4.4 (A), U1.5 (GND), U3.7 (Vss), U4.12 (Vdd), U5.10 (P0), U5.12 (Vdd), U6.12 (Vdd), U7.10 (P0), U7.12 (Vdd), U8.12 (Vdd), U11.3 (V-), U20.40 (Vdd)
/ClockGen/CLK1: R14.2, U4.6 (CLK1), U5.6 (CLK1), U6.6 (CLK1), U7.6 (CLK1), U8.6 (CLK1), U20.13 (CLK1)
/ClockGen/CLK2: R15.2, U4.7 (CLK2), U5.7 (CLK2), U6.7 (CLK2), U7.7 (CLK2), U8.7 (CLK2), U20.14 (CLK2)
/ProgramMemory/CM: U4.11 (CMROM), U20.16 (CM)
/ProgramMemory/D0: U4.1 (D0), U5.1 (D0), U6.1 (D0), U7.1 (D0), U8.1 (D0), U20.1 (D0)
/ProgramMemory/D1: U4.2 (D1), U5.2 (D1), U6.2 (D1), U7.2 (D1), U8.2 (D1), U20.2 (D1)
/ProgramMemory/D2: U4.3 (D2), U5.3 (D2), U6.3 (D2), U7.3 (D2), U8.3 (D2), U20.3 (D2)
/ProgramMemory/D3: U4.4 (D3), U5.4 (D3), U6.4 (D3), U7.4 (D3), U8.4 (D3), U20.4 (D3)
/ProgramMemory/RESET: U3.3, U4.9 (RESET), U5.9 (RESET), U6.9 (RESET), U7.9 (RESET), U8.9 (RESET), U20.17 (RESET)
/ProgramMemory/SYNC: U4.8 (SYNC), U5.8 (SYNC), U6.8 (SYNC), U7.8 (SYNC), U8.8 (SYNC), U20.15 (SYNC)
BANK0: D18.1 (K), R27.1, U8.16 (O0)
BANK1: D19.1 (K), R26.1, U8.15 (O1)
BANK2: D20.1 (K), R25.1, U8.14 (O2)
BANK3: D21.1 (K), R24.1, U8.13 (O3)
BANK4: D14.1 (K), R23.1, U7.16 (O0)
BANK5: D15.1 (K), R22.1, U7.15 (O1)
BANK6: D16.1 (K), R21.1, U7.14 (O2)
BANK7: D17.1 (K), R20.1, U7.13 (O3)
C0: U14.9, U16.25 (A8), U20.31 (C0)
C1: U14.10, U16.24 (A9), U20.32 (C1)
C2: U14.12, U16.21 (A10), U20.33 (C2)
C3: U14.13, U16.23 (A11), U20.34 (C3)
CMRAM0: J2.1, U4.16 (CMRAM0), U7.11 (CM), U8.11 (CM)
CMRAM1: J2.3, U4.15 (CMRAM1)
CM_RAM23: J2.2, U5.11 (CM), U6.11 (CM)
GND: C5.2, C6.2, C7.1, C11.1, C12.2, C18.2, C19.2, C20.2, C21.2, C22.2, C23.1, C24.2, C25.1, D1.2 (A), D2.2 (A), D3.2 (A), D4.2 (A), D22.2 (A), D23.2 (A), D24.2 (A), D25.2 (A), D26.2 (A), D27.2 (A), D28.2 (A), D29.2 (A), D30.2 (A), D31.2 (A), D32.2 (A), D33.2 (A), D34.1 (K), D35.2 (A), D36.1 (K), J3.1, J5.1, R29.1, R30.1, R31.1, R38.1, SW3.5, U9.7 (GND), U10.7 (GND), U12.3 (A), U12.4 (B), U12.5 (C), U12.6 (D), U12.8 (GND), U13.7 (GND), U14.7 (GND), U15.7 (GND), U16.14 (Vss(GND)), U17.14 (Vss(GND)), U17.26 (A16), U17.27 (A17), U18.14 (Vss(GND)), U18.26 (A16), U18.27 (A17), U19.10 (GND), U20.35 (Vdd1)
GND2: C2.1, D5.1 (K), J1.1, U2.5 (GND)
unnamed: C3.1, R8.2, R9.2, U3.13
unnamed: C4.1, R10.2, R11.2, R12.1, U3.5, U3.6
unnamed: C8.1, U9.8
unnamed: C9.1, U9.10
unnamed: C10.1, R16.2, U9.2
unnamed: C10.2, R17.1, U9.3
unnamed: C12.1, R16.1, U9.1, Y1.1
unnamed: D1.1 (K), J3.2, R1.2
unnamed: D2.1 (K), J3.4, R2.2
unnamed: D3.1 (K), J3.6, R3.2
unnamed: D4.1 (K), J3.8, R4.2
unnamed: D5.2 (A), R5.1
unnamed: D6.2 (A), RN1.2 (R1)
unnamed: D6.1 (K), U3.8, U3.9, U5.16 (O0)
unnamed: D7.2 (A), RN1.3 (R2)
unnamed: D7.1 (K), U5.15 (O1)
unnamed: D8.2 (A), RN1.4 (R3)
unnamed: D8.1 (K), U5.14 (O2)
unnamed: D9.2 (A), RN1.5 (R4)
unnamed: D9.1 (K), U5.13 (O3)
unnamed: D10.2 (A), RN2.2 (R1)
unnamed: D11.2 (A), RN2.3 (R2)
unnamed: D12.2 (A), RN2.4 (R3)
unnamed: D13.2 (A), RN2.5 (R4)
unnamed: D14.2 (A), RN3.2 (R1)
unnamed: D15.2 (A), RN3.3 (R2)
unnamed: D16.2 (A), RN3.4 (R3)
unnamed: D17.2 (A), RN3.5 (R4)
unnamed: D18.2 (A), RN4.2 (R1)
unnamed: D19.2 (A), RN4.3 (R2)
unnamed: D20.2 (A), RN4.4 (R3)
unnamed: D21.2 (A), RN4.5 (R4)
unnamed: D22.1 (K), R27.2, U17.9 (A8), U18.9 (A8)
unnamed: D23.1 (K), R26.2, U17.10 (A9), U18.10 (A9)
unnamed: D24.1 (K), R25.2, U17.11 (A10), U18.11 (A10)
unnamed: D25.1 (K), R24.2, U17.21 (A11), U18.21 (A11)
unnamed: D26.1 (K), R23.2, U17.22 (A12), U18.22 (A12)
unnamed: D27.1 (K), R22.2, U17.23 (A13), U18.23 (A13)
unnamed: D28.1 (K), R21.2, U17.24 (A14), U18.24 (A14)
unnamed: D29.1 (K), R20.2, U17.25 (A15), U18.25 (A15)
unnamed: D30.1 (K), R32.2, U19.2 (A0), U19.6 (A4)
unnamed: D31.1 (K), R33.2, U19.3 (A1), U19.7 (A5)
unnamed: D32.1 (K), R34.2, U19.4 (A2), U19.8 (A6)
unnamed: D33.1 (K), R35.2, U19.5 (A3), U19.9 (A7)
unnamed: D34.2 (A), R36.2
unnamed: D35.1 (K), J4.1, R37.1, SW4.2 (B)
unnamed: D36.2 (A), D37.1 (K), J6.1, SW4.5 (B)
unnamed: D37.2 (A), R37.2
unnamed: D38.2 (A), R38.2
unnamed: J1.4, R6.1
unnamed: J1.5, U2.6 (Vo)
unnamed: R7.1, U3.10
unnamed: R9.1, SW1.2
unnamed: R11.1, SW2.2
unnamed: R17.2, U9.4, U10.1, U10.2, Y1.2
unnamed: R6.2, U1.3 (K)
unnamed: U1.6 (Vo), U3.12
unnamed: R7.2, U2.3 (K)
unnamed: U3.1, U3.2, U3.4
unnamed: U3.11, U4.10 (TEST)
unnamed: U9.11, U10.8
unnamed: U9.12, U10.10, U10.12
unnamed: U9.9, U10.11
unnamed: U9.6, U10.13
unnamed: C8.2, U11.2 (IN_A)
unnamed: C9.2, U11.4 (IN_B)
unnamed: R14.1, R18.2, U11.7 (OUT_A)
unnamed: R15.1, R19.2, U11.5 (OUT_B)
unnamed: U10.3, U12.2 (CLOCK)
unnamed: R13.1, U12.1 (~CLEAR), U12.7 (EP), U12.10 (ET)
unnamed: U10.6, U12.9 (LOAD)
unnamed: U9.13, U10.4, U12.13 (QB)
unnamed: U9.5, U10.5, U10.9, U12.12 (QC)
unnamed: U13.4, U14.4
unnamed: U14.2, U14.5, U15.1
unnamed: U14.8, U15.8
unnamed: U14.11, U15.9
unnamed: U16.10 (A0), U17.1 (A0), U18.1 (A0), U20.23 (A0)
unnamed: U16.9 (A1), U17.2 (A1), U18.2 (A1), U20.24 (A1)
unnamed: U16.8 (A2), U17.3 (A2), U18.3 (A2), U20.25 (A2)
unnamed: U16.7 (A3), U17.4 (A3), U18.4 (A3), U20.26 (A3)
unnamed: U16.6 (A4), U17.5 (A4), U18.5 (A4), U20.27 (A4)
unnamed: U16.5 (A5), U17.6 (A5), U18.6 (A5), U20.28 (A5)
unnamed: U16.4 (A6), U17.7 (A6), U18.7 (A6), U20.29 (A6)
unnamed: U16.3 (A7), U17.8 (A7), U18.8 (A7), U20.30 (A7)
unnamed: U16.11 (D0), U17.19 (I/O1), U19.18 (Y0), U20.9 (OPA0)
unnamed: U16.12 (D1), U17.18 (I/O2), U19.17 (Y1), U20.10 (OPA1)
unnamed: U16.13 (D2), U17.17 (I/O3), U19.16 (Y2), U20.11 (OPA2)
unnamed: U16.15 (D3), U17.16 (I/O4), U19.15 (Y3), U20.12 (OPA3)
unnamed: U16.16 (D4), U18.19 (I/O1), U19.14 (Y4), U20.5 (OPR0)
unnamed: U16.17 (D5), U18.18 (I/O2), U19.13 (Y5), U20.6 (OPR1)
unnamed: U16.18 (D6), U18.17 (I/O3), U19.12 (Y6), U20.7 (OPR2)
unnamed: U16.19 (D7), U18.16 (I/O4), U19.11 (Y7), U20.8 (OPR3)
unnamed: U13.1, U15.3, U19.1 (G1), U20.19 (OUT)
unnamed: U15.2, U19.19 (G2), U20.21 (PM)
unnamed: U13.3, U14.1, U20.22 (FL)
unnamed: R32.1, U20.39 (I/O1)
unnamed: R33.1, U20.38 (I/O2)
unnamed: R34.1, U20.37 (I/O3)
unnamed: R35.1, U20.36 (I/O4)
RAM2-0: D10.1 (K), R1.1, U6.16 (O0)
RAM2-1: D11.1 (K), R2.1, U6.15 (O1)
RAM2-2: D12.1 (K), R3.1, U6.14 (O2)
RAM2-3: D13.1 (K), R4.1, U6.13 (O3)
ROM_P1: R31.2, SW3.1, U16.1 (NC)
ROM_P2: R30.2, SW3.2, U16.2 (A12)
ROM_P26: R29.2, SW3.3, U16.26 (NC)
ROM_P27: R28.1, SW3.4, U16.27 (~WE)
VBUS: C2.2, J1.3, R5.2, U1.2 (A), U2.8 (VDD)
~CS_RAM: U13.6, U17.12 (~CS), U18.12 (~CS)
~CS_ROM: U13.5, U15.10, U16.20 (~CS)
~OE: U13.2, U16.22 (~OE), U17.13 (~OE), U18.13 (~OE)
~WE_OPA: U14.3, U17.15 (~WE)
~WE_OPR: U14.6, U18.15 (~WE)

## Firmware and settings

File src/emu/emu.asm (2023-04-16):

;;;---------------------------------------------------------------------------
;;; Tiny Monitor with 8080 emulator on 4004 (emu8080)
;;; for Intel 4004 evaluation board
;;;
;;; by Ryo Mukai
;;; 2023/04/16
;;;---------------------------------------------------------------------------

;;;---------------------------------------------------------------------------
;;; This source can be assembled with the Macroassembler AS
;;; (http://john.ccac.rwth-aachen.de:8000/as/)
;;;---------------------------------------------------------------------------

	cpu 4004	; AS's command to specify CPU

	include "macros.inc"	; aliases and macros

;;;---------------------------------------------------------------------------
;;; Software Configuration
;;;---------------------------------------------------------------------------

USE_MON_CMD_DP = 0		; dump physical memory command 'DP'
USE_MON_CMD_T = 0		; memory test command 'T'

;;;---------------------------------------------------------------------------
;;; Emulator compile configuration
;;;---------------------------------------------------------------------------
;; FLAG_P is not implemented because it takes much cost
USE_EMU_FLAG_P = 1	; use P FLAG

;;;---------------------------------------------------------------------------
;;; Emulator port configuration
;;;---------------------------------------------------------------------------
;;; EMU_UARTRC	equ	00H	; for tinybasic-1.0
;;; EMU_UARTRD	equ	01H	; for tynybasic-1.0
;;; EMU_IN_UARTRC_VALUE	equ 22H	 ; for tynybasic-1.0

EMU_UARTRC	equ	01H	; for SBC8080 compatibility
EMU_UARTRD	equ	00H	; for SBC8080 compatibility
EMU_IN_UARTRC_VALUE	equ 0FFH	;
EMU_IN_STOPCODE	equ 03H			; ctrl-C
	
;;;---------------------------------------------------------------------------
;;; Hardware Configuration
;;;---------------------------------------------------------------------------

;;; RAM0 and RAM1 must be 4002-1 and located in the BANK#0 (CM-RAM0).
;;; For RAM2 and RAM3, 4002-2 is preferred, because it can be located
;;; in the BANK#0 same as RAM0 and RAM1.
;;; However -2 is more expensive and difficult to get than -1,
;;; so the chip type of RAM2 and RAM3 is configurable.
;;; If you use -1 for RAM2 and RAM3, they are located in
;;; the BANK#1 (CM-RAM1), and DCL must be executed before SRC.

;;; Chip type of RAM2 and RAM3
RAM23TYPE	equ "4002-2"	; or "4002-1"

;;; BANK# for DCL, and CHIP#=(D7.D6.000000) for SRC
BANK_RAM0	equ 0
CHIP_RAM0	equ 00H
BANK_RAM1	equ 0
CHIP_RAM1	equ 40H
	if (RAM23TYPE == "4002-2")
BANK_RAM2	equ 0
CHIP_RAM2	equ 80H
BANK_RAM3	equ 0
CHIP_RAM3	equ 0C0H
	elseif (RAM23TYPE == "4002-1")
BANK_RAM2	equ 1
CHIP_RAM2	equ 00H
BANK_RAM3	equ 1
CHIP_RAM3	equ 40H
	endif

;;; Default Bank
;;; The CM-RAM line should be always set to BANK_DEFAULT
;;; to omit DCL as much as possible.
;;; (This is for when RAM23TYPE=="4002-1".)
BANK_DEFAULT	equ BANK_RAM0
		
;;; Output port for serial interface
BANK_SERIAL	equ BANK_RAM3
CHIP_SERIAL	equ CHIP_RAM3

;;; Output port for program memory bank selection
BANK_PMSELECT0	equ BANK_RAM0
BANK_PMSELECT1	equ BANK_RAM1
CHIP_PMSELECT0	equ CHIP_RAM0
CHIP_PMSELECT1	equ CHIP_RAM1

	
;;; Program Memory RAM area
PM_RAM_START	equ 0F00H	; Start address of program memory RAM
PM_READ_P0_P1	equ 0FFEH	; Entry of the subroutine to read RAM
				; "FIN P1 and BBL 0"
	
;;; Address labels in the 16 bit address space logical program memory PM16
PM16_MEMSTART	equ 0000H
PM16_LINEBUF	equ 0FD00H

;;; for 256 x 16 x16 PM space
;;; PM_READ_P0_P1   equ 0F7EH	; Entry of the subroutine to read RAM
;;; PM16_LINEBUF	equ 7D00H

;;;---------------------------------------------------------------------------
;;; Data RAM Register Configuration
;;;---------------------------------------------------------------------------
;;; RAM0
;;; 
;;; 8080 register code DDD or SSS
;;; 0 1 2 3 4 5 6 7
;;; B C D E H L M A
;;; 
;;;  ADDRESS=~(xxx)<<1
	
REG8_A		equ 00H	;
REG8_M		equ 02H	; REG8_M is only used as a label.
REG8_L		equ 04H	;
REG8_H		equ 06H	;
REG8_E		equ 08H	;
REG8_D		equ 0AH	;
REG8_C		equ 0CH	;
REG8_B		equ 0EH	;

REG8_FLAG	equ 10H ;
REG8_SRC	equ 12H	; temporary register to save SRC reg value
REG16_PC	equ 14H	; Program Counter of 8080
REG16_SP	equ 18H	; Stack Pointer of 8080
REG16_ADDR	equ 1CH ; 16 bit temporary register

		;; lower byte is the first
REG16_BC	equ REG8_C
REG16_DE	equ REG8_E
REG16_HL	equ REG8_L

REG8_PCL	equ REG16_PC
REG8_PCH	equ REG16_PC+2
REG8_SPL	equ REG16_SP
REG8_SPH	equ REG16_SP+2
REG8_ADDRL	equ REG16_ADDR
REG8_ADDRH	equ REG16_ADDR+2
	
REG4_FLAG_1P1C	equ REG8_FLAG
REG4_FLAG_SZBH	equ REG8_FLAG+1

REG8_EMU_KEYBUF equ 20H ; virtual buffer for input STOP key
REG4_EMU_MODE	equ 24H	; Execution mode (0:continuous, 1:viewPC, 2:step)
	
REG16_MON_INDEX	equ 28H	;
REG16_MON_ADDR	equ 2CH	;
REG16_MON_TMP	equ 30H	;
REG8_MON_TMP	equ 30H	;
REG8_MON_TMP2	equ 32H	;
REG16_MON_PMBANK	equ 34H	; not used (?)
REG8_MON_MEMSPACE	equ 38H	; 'D', 'P', 'L' = (Data, Physical, Logical)
REG8_MON_RESERVED	equ 3AH	; (reserved)
	

;;; RAM1
REG16_STACK_40H	equ 40H		;; stack area
REG16_STACK_7CH	equ 7CH	

STACK_INIT	equ 80H

;;; RAM2
;;; RAM3
	
;;;---------------------------------------------------------------------------
;;; Program Start
;;;---------------------------------------------------------------------------
	org 0000H		; beginning of Program Memory

;;;---------------------------------------------------------------------------
;;; Mail Loop for Monitor Program
;;; 
;;; Command:
;;; H : Select memory space
;;;   HD : Data RAM (4002)
;;;   HP : Physical Program Memory
;;;   HL : Logical Program Memory
;;; D : Dump memory
;;; L : Load Intel hex to logical program memory
;;; C : Clear Program Memory
;;; G : Go to PM_RAM_START (0F00H)
;;; E : 8080 Emulator
;;;   ES : 8080 Emulator (step mode)
;;; 
;;;---------------------------------------------------------------------------
MAIN:
	NOP
	CLB

	if ( BANK_DEFAULT != 0 )
	LDM BANK_DEFAULT
	endif
	;; DL is assumed to be set back to BANK_DEFAULT (normally 0)
	;; except when in use for another banks.
	DCL

	FIM SP, STACK_INIT	; initialize stack pointer
	JMS INIT_SERIAL		; Initialize Serial Port


	;; write "PM_READ_P0_P1" routine on all memory banks
	LDM loop(16)
	XCH P1_HI
PM_INIT_HLOOP:
	LDM loop(16)
	XCH P1_LO
PM_INIT_LLOOP:
	JMS PM_SELECTPMB_P1
	JMS PM_INIT_BANK ; write PM_READ code on program memory
	ISZ P1_LO, PM_INIT_LLOOP
	ISZ P1_HI, PM_INIT_HLOOP

	FIM P1, 00H
	JMS PM_SELECTPMB_P1	 ; set PMB to 0
	
;	JCN TN, $		;wait for TEST="0" (button pressed)
	FIM P0, lo(STR_VFD_INIT) ; init VFD
	JMS PRINTSTR_P0
	FIM P0, lo(STR_OMSG) ; opening message in the Page 7
	JMS PRINTSTR_P0

	FIM P0, REG8_MON_MEMSPACE
	FIM P1, 'D'
	JMS LD_REG8P0_P1	; set memspace 'D'
	
	;; init emulator PC
	FIM P0, REG16_PC
	FIM P2, 00H
	FIM P3, 00H
	JMS LD_REG16P0_P2P3	; PC=0000H
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

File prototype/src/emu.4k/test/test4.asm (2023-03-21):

;;; test4.asm
;;; 
;;; ADD, ADC, SUB, SBB

	CPU	8080
START:
;;; ----------------------------------
	MVI A, 11H
	MVI B, 22H
	ADD B			;A=33H

	MVI A, 0F0H
	MVI C, 11H
	ADD C			;A=01H,CY=1

	MVI A, 0F0H
	MVI D, 00FH
	ADD D			;A=FF,CY=0

	XRA A			;A=00,CY=0
	MVI A, 0F0H		;
	MVI E, 0FH
	ADD E			;A=FF
;;; ----------------------------------
	MVI A, 11H
	MVI B, 22H
	ADC B			;A=33H

	MVI A, 0F0H
	MVI C, 11H
	ADC C			;A=01H

	STC			;CY=1
	MVI A, 0F0H
	MVI D, 0FH
	ADC D			;A=00

	XRA A			;CY=0
	MVI A, 0F0H
	MVI E, 0FH
	ADC E			;A=FF
;;; ----------------------------------
	MVI A, 33H
	MVI B, 11H
	SUB B			;A=22H

	MVI A, 10H
	MVI C, 11H
	SUB C			;A=FFH,CY=1

	STC
	MVI A, 10H
	MVI D, 10H
	SUB D			;A=00,CY=0

	XRA A
	MVI A, 10H
	MVI E, 10H
	SUB E			;A=00,CY=0
;;; ----------------------------------
	MVI A, 33H
	MVI B, 11H
	SBB B			;A=22

	MVI A, 10H
	MVI C, 11H
	SBB C			;A=FF,CY=1

	STC
	MVI A, 10H
	MVI D, 10H
	SBB D			;A=FF,CY=1

	XRA A
	MVI A, 10H
	MVI E, 10H
	SBB E			;A=0,CY=0
;;; ----------------------------------
	LXI H, 0ABCH
	MVI M, 11H
	MVI A, 0FFH
	SUB M
	SUB M
	SUB M
	SUB M
	SUB M
	
	HLT

	END
	

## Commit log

2023-04-03 add errorcheck in getline
    [emu.asm]
2023-04-12 update for rev2.1
    [ClockGen.kicad_sch, ProgramMemory_sch.kicad_sch, misc.kicad_sch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]
